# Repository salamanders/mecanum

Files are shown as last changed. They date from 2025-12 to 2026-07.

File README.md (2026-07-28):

# Robot Twin Stick Controller

4 mecanum wheel robot controlled by a twin stick controller UI.

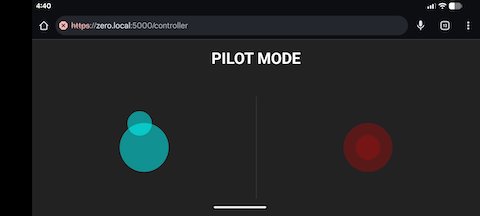
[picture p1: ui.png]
ui


## System Architecture

```mermaid
graph TD
    subgraph Client ["Client Device (Phone / Control Device)"]
        UI["controller.html (Manual twin-stick UI)"]
        Sensor["sensor.html (Sends Phone Compass data)"]
        Face["face.html (Planned: Face/Vision client)"]:::planned
    end

    subgraph Backend ["Raspberry Pi Server (app.py)"]
        Flask["Flask & SocketIO Server"]
        Wifi["WifiManager (wifi_manager.py)"]
        Driver["MotorDriver (motor_driver.py)"]
        Auto["Auto Mode Controller (Planned)"]:::planned
    end

    subgraph Hardware ["Robot Hardware"]
        I2C["I2C Bus"]
        Motors["Motors (M1, M2, M3, M4)"]
    end

    UI -- "joystick_data" --> Flask
    Sensor -- "sensor_data" --> Flask
    Face -. "face_data (planned)" .-> Flask
    Flask -- "drive(speeds)" --> Driver
    Auto -. "drive(speeds)" .-> Driver
    Driver -- "I2C Commands" --> I2C
    I2C --> Motors
    Wifi -- "nmcli commands" --> OS["OS NetworkManager"]

    classDef planned stroke-dasharray: 5 5,stroke:#999,fill:#fafafa;
```

## Getting Started

### Prerequisites

* Python 3.7+
* Hardware:
    * Raspberry Pi Zero 2 W with the default Raspbian
    * Motor Bonnet
    * Mecanum wheels (4 total, 2 of each type)
    * USB Battery pack
    * USB PD (Power Delivery) Decoy Trigger (set to 9V)
    * IMU (optional) or Android Phone (Pixel 4 etc.) for compass
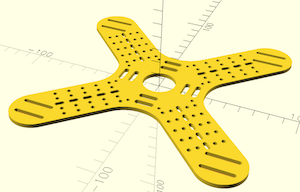
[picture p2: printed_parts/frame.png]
model
    * Some sort of frame: model included <br/> 

### System Dependencies (Raspberry Pi)

For hardware access on Raspberry Pi:

```bash
sudo raspi-config nonint do_i2c 0
```

**Wi-Fi Management:**
The robot uses `nmcli` (NetworkManager) to manage connections. Ensure it is installed:

```bash
sudo apt install network-manager
```

Then run the script in [AGENTS.md](AGENTS.md).

### Wi-Fi Fallback Mode

If the robot cannot connect to a known Wi-Fi network on boot, it will create a Hotspot:

* **SSID:** `RobotHotspot`
* **Password:** `password`
* **IP:** `10.42.0.1` (usually)

Connect your phone to this hotspot, then visit:
`http://10.42.0.1:5000/wifi`

From there, you can scan for networks and configure the robot to connect to a new location.

```mermaid
flowchart TD
    Start([System Boot]) --> CheckFlag{force_hotspot.flag exists?}
    
    CheckFlag -- Yes --> CheckLog{wifi.log writable?}
    CheckLog -- No --> PrintErr["Log error to stderr"] --> BootWait["Wait boot_wait (15s)"]
    CheckLog -- Yes --> ConsumeFlag{Can delete flag file?}
    
    ConsumeFlag -- Yes --> ForceHotspot["Set force_hotspot = True"] --> ForceAP["Trigger ensure_hotspot() immediately"]
    ConsumeFlag -- No --> LogErr["Log permission error"] --> BootWait
    
    CheckFlag -- No --> BootWait
    
    BootWait --> NormalLoop["Start normal monitoring loop"]
    NormalLoop --> QueryStatus["Query connection status"]
    
    QueryStatus --> Connected{Connected to Wi-Fi?}
    Connected -- Yes --> LoopSleep["Sleep check_interval (30s)"] --> QueryStatus
    Connected -- No --> ActivateAP["Trigger ensure_hotspot()"] --> LoopSleep
    
    ForceAP --> LoopSleep
```

#### Forcing Hotspot Mode

There are two easy ways to force the robot into Hotspot mode:

1. **Web UI Button (Instant Switch):** Visit `https://<ip>:5000/wifi` while connected and click the **"Switch to Hotspot"** button. The robot instantly switches to `RobotHotspot` mode without requiring a reboot, and writes `force_hotspot.flag` for one-time boot persistence.
2. **Command / Flag File (One-Time Boot Force):** Touch `force_hotspot.flag` in the project root directory:
   ```bash
   touch force_hotspot.flag
   ```
   On the next boot, `wifi_monitor.py` will detect the flag, immediately delete it to prevent lockout loops, and boot straight into hotspot mode. On subsequent reboots, normal Wi-Fi auto-connect resumes.
   * **Permissions Note:** The Linux user running the robot service (defined as `User` in `robot.service`, typically `pi`) must have write/delete permissions in the project root directory to delete the flag file and log to `wifi.log`.

### Installation

1. Clone the repo.
2. Install Python dependencies:

```bash
make install
```

### Running the Robot

Start the server:

```bash
make run
```

Then visit `https://zero.local:5000/controller` on your phone.

### Auto-Start Service

To run the robot automatically on boot, see [AUTO_RUN.md](AUTO_RUN.md).

### Development & Mock Mode

By default, motor control supports mock execution via `force_mock.flag` or command line flags when hardware is disconnected.

For Wi-Fi management, `WifiManager` operates directly via `nmcli` without internal fake mock state branches. If `nmcli` is not installed (e.g. running locally on a non-Linux development laptop), `WifiManager` returns clean error status responses without crashing or corrupting state.

To force mock mode for motor drivers during local development:

1. Create a `force_mock.flag` file in the project root:
   ```bash
   touch force_mock.flag
   ```
2. Run the application (`make run` or `python3 app.py`).
3. The server detects the flag, deletes it, and runs motor drivers in mock mode for that session.

To lint the code:

```bash
make lint
```

### Testing

To test motor mappings (or check Mock output):

```bash
make test
```

## Hardware Setup

* **Power**: Set USB PD Trigger to 9V.
* **Layout**: Ensure Mecanum wheels form an 'X' pattern from the top.
* **Wiring**: Connect your 4 motor channels to terminals M1-M4. Run `python3 wiring_check.py` to interactively calibrate motor channel positions and spin directions without physically rewiring.

## Files

### Backend & Hardware

* `app.py`: Main Flask application. Handles SocketIO communication, robot state management, and HTTPS certificate
  generation.
* `motor_driver.py`: Hardware abstraction layer. Handles `adafruit-circuitpython-motorkit` interaction, configurable motor channel/direction mapping, and automatic Mock fallback.
* `wiring_check.py`: Interactive calibration wizard to test channels, assign motor positions and rotation directions, and generate `motor_config.json`.

### Frontend

* `templates/`
    * `controller.html`: The Twin-Stick Joystick UI structure.
    * `sensor.html`: The Sensor Client UI structure (for transmitting phone compass/accelerometer data).
* `static/js/`
    * `common.js`: Shared logic for SocketIO connection and UI status updates.
    * `controller.js`: Handles Nipple.js joystick input and transmission.
    * `sensor.js`: Handles DeviceOrientation/Motion events and permission requests (iOS support).

### Configuration

* `Makefile`: Shortcuts for common commands (`install`, `run`, `test`, `lint`).
* `motor_config.json`: Recorded channel mapping and direction inversion config (generated by `wiring_check.py`).
* `pyproject.toml`: Python dependency management and project configuration.

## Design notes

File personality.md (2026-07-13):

# Robot Personality & Autonomous Vision Design

## Overview

This document describes the design for the robot's "Personality" system, which uses a permanently mounted Android phone
to act as the robot's face, sensor package, and autonomous brain.

The system adds expressiveness via an animated eye display and enables autonomous "chasing" behavior using web-based
computer vision, while maintaining a safety override for manual control.

## Hardware Setup

- **Device:** Android Phone (permanent fixture).
- **Mount:** Forward-facing, displaying the screen to the world (acting as "Eyes") and using the rear camera for vision.
- **Connectivity:** Connected to the robot's local Wi-Fi, accessing the web interface.

## Software Architecture

### 1. Unified Client Interface (`face.html`)

A single web page serves three distinct roles:

1. **The Face:** Displays animated eyes (CSS/SVG) that react to robot state and look at detected objects.
2. **The Sensor:** Reads device IMU data (DeviceMotion/DeviceOrientation) for compass/gyro headers (replacing
   `sensor.html`).
3. **The Vision System:** Runs a local JavaScript Object Detection model (TensorFlow.js / COCO-SSD) to detect people or
   objects.

### 2. Autonomous Logic (Client-Side)

- **Object Detection:** The phone captures video frames and processes them locally using TF.js.
- **Target Selection:** The logic selects the "most interesting" object (e.g., the largest "person" or a specific
  color).
- **Data Transmission:** The client sends a `face_data` packet to the backend ~100ms:
  ```json
  {
    "alpha": 120.5,       // Compass heading (from IMU)
    "beta": 10.2,         // Pitch (from IMU)
    "gamma": -5.0,        // Roll (from IMU)
    "vision": {
      "detected": true,
      "type": "person",
      "x": 0.5,           // Normalized X center (0.0 - 1.0)
      "y": 0.4,           // Normalized Y center (0.0 - 1.0)
      "size": 0.3         // Normalized area/height
    }
  }
  ```

### 3. Backend Logic (`app.py`)

The Python backend handles the "Safety Override" and kinematic control.

#### Safety Arbitration

- **Rule:** Human control via `/controller` always takes precedence.
- **Mechanism:**
    - A timestamp `last_human_command_time` is updated whenever a joystick event is received.
    - If `current_time - last_human_command_time < 60 seconds`:
        - **Manual Mode:** The robot ignores `vision` driving commands.
        - The `robot_status` broadcast includes `"mode": "manual"`.
    - If `current_time - last_human_command_time >= 60 seconds`:
        - **Autonomous Mode:** The robot calculates motor speeds based on `vision` data.
        - The `robot_status` broadcast includes `"mode": "auto"`.

```mermaid
stateDiagram-v2
    [*] --> ManualMode : System Start
    
    state ManualMode {
        [*] --> Idle
        Idle --> Moving : Joystick Input Received
        Moving --> Idle : Joystick Stopped
    }

    ManualMode --> AutoMode : 60 Seconds of Inactivity (No Joystick Inputs)
    
    state AutoMode {
        [*] --> Scanning
        Scanning --> Chasing : Object Detected
        Chasing --> Scanning : Target Lost
    }

    AutoMode --> ManualMode : Joystick Input Received (Manual Override)
```

#### Chasing Behavior (Auto Mode)

- **Turn:** Proportional control to center the object (Target X = 0.5).
- **Drive:** Proportional control to maintain a target size (e.g., move forward if size < 0.5, stop if close).

## Visual Personality

- **Idle/Manual Mode:** Eyes look around randomly or track the last known heading.
- **Auto Mode:** Eyes "lock on" to the detected object (tracking X/Y coordinates).
- **Reactions:**
    - Squint when moving fast.
    - Blink randomly.
    - Change color/shape based on "mode" (e.g., Blue for Manual, Red for Auto/Chasing).

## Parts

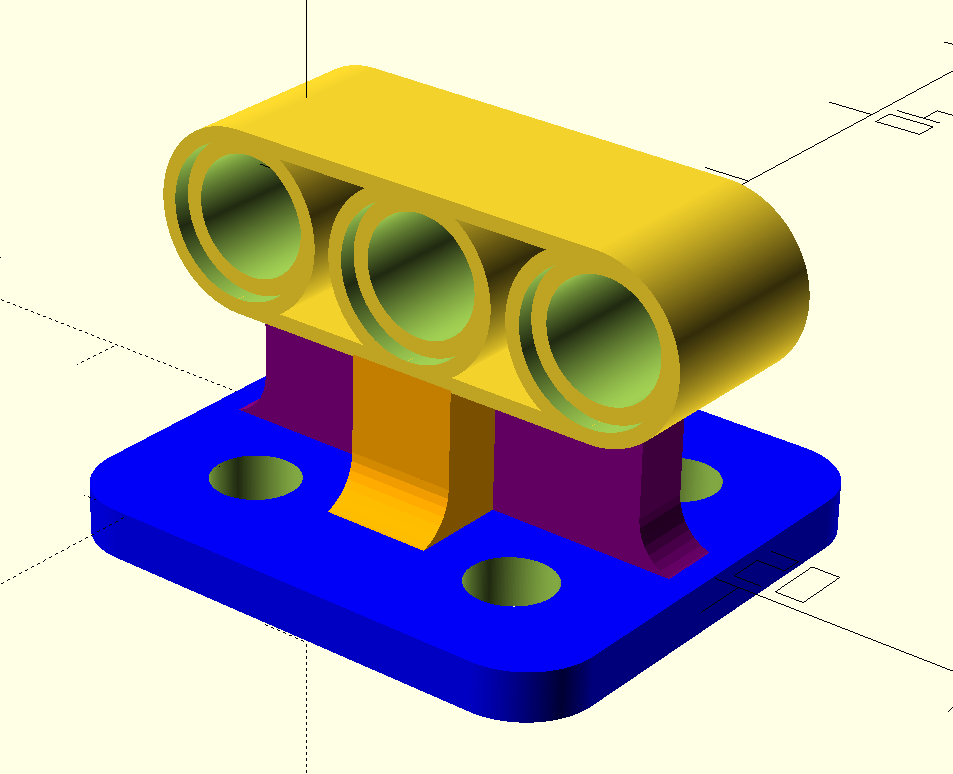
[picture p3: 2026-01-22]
printed_parts/motor_technic.png

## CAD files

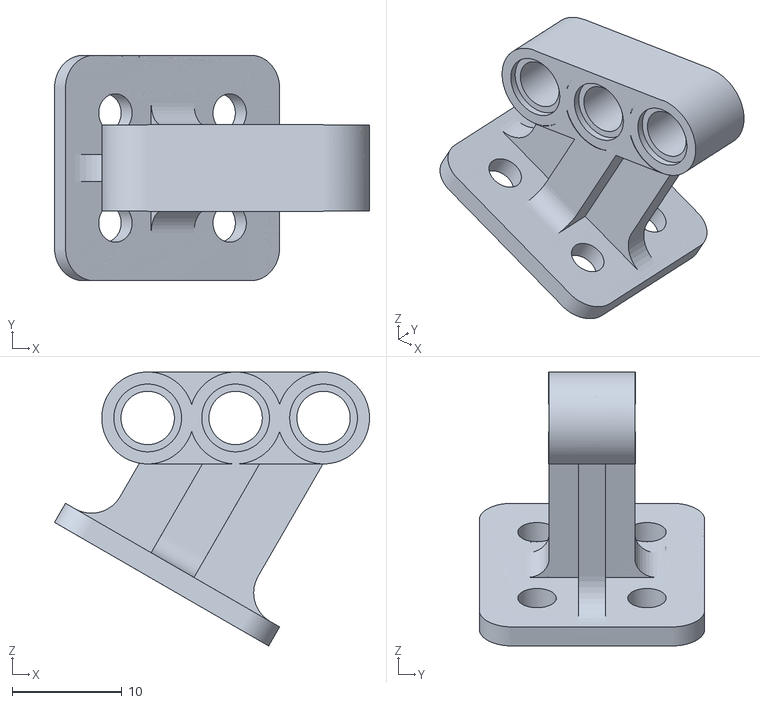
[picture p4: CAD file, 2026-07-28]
printed_parts/motor_technic.stl
28.7 x 20.5 x 24.9

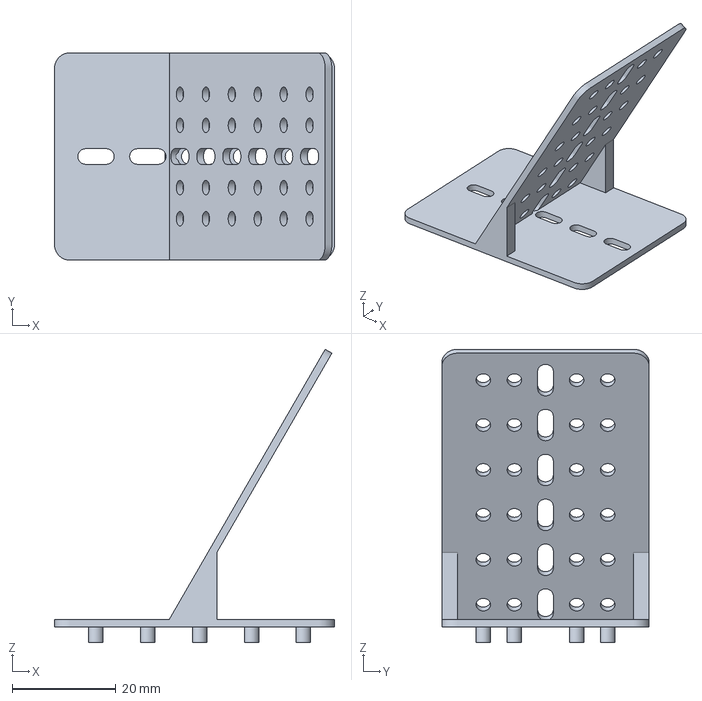
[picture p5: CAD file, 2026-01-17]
printed_parts/angled_clip.3mf
54.0 x 40.0 x 56.6 mm

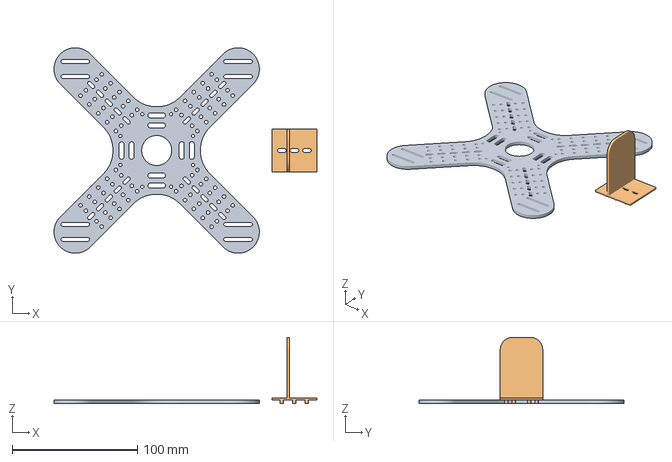
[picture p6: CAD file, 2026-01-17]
printed_parts/frame.3mf
210.0 x 164.0 x 53.0 mm

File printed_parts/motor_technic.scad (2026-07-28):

include <Technic.scad>
include <BOSL2/std.scad>

plate_height = 2;
neck_height = 6;
conn_h = 20; // Extended height to reach across the 30-degree tilt

// Square of 4 screw holes, measuring from the edges of the holes.
screw_outer_dist_x = 15.5;
screw_inner_dist_x = 8.5;

screw_outer_dist_y = 13.5;
screw_inner_dist_y = 6.5;

screw_d = 3.5;

technic_pin_connector_outer_diameter = 7.36 + 1;
technic_pin_connector_shoulder_wall_thickness = 0.6 + 0.5;

//technic_pin_connector_outer_diameter = 9.36;
//technic_pin_connector_shoulder_wall_thickness = 1.6;

union() {
    // Yellow Technic Beam
    translate([4.5,0,0])
    translate([0, technic_height_in_mm/2, technic_beam_hole_spacing/2 + neck_height - 0.4])
    rotate([90,0,0])
    technic_beam(length = 3);

    // Connectors: Built on top of the rotated plate surface and trimmed flat at neck_height
    difference() {
        rotate([0,30,0]) {
            // Orange Connector
            color("orange")
            translate([screw_outer_dist_x/2, 0, 0.1 + conn_h/2])
            cuboid(
                [screw_inner_dist_x - 4, technic_height_in_mm, conn_h], 
                rounding = -2,
                edges = [BOT], 
                except = [LEFT, RIGHT],
                $fn = 36
            );

            // Purple Connectors
            p_adjust = -1.0;
            
            color("purple")
            translate([screw_outer_dist_x/2, 0, 0.1 + conn_h/2])
            cube([screw_outer_dist_x + p_adjust, screw_inner_dist_y - 4, conn_h], center = true);

            color("purple")
            translate([screw_outer_dist_x/2, 0, 0.1 + conn_h/2])
            cuboid(
                [screw_outer_dist_x + p_adjust, screw_inner_dist_y - 4, conn_h], 
                rounding = -3,
                edges = [BOT], 
                except = [FRONT, BACK],
                $fn = 36
            );
        }

        // Trim any connector material extending above the top neck line (Z >= neck_height)
        translate([0, 0, neck_height + 25])
        cube([100, 100, 50], center = true);
    }

    // Blue Plate
    rotate([0,30,0])
    translate([0, -screw_d - screw_inner_dist_y/2, -plate_height + 0.1])
    difference() {
        color("blue")
        translate([screw_outer_dist_x/2, screw_outer_dist_y/2, plate_height/2])
        cuboid(
            [screw_outer_dist_x + 2*screw_d, screw_outer_dist_y + 2*screw_d, plate_height], 
            rounding = 3, 
            except = [TOP, BOT]
        );

        translate([0, 0, -1]) {
            translate([screw_d/2, screw_d/2, 0])
            cylinder(h = 5, d = screw_d);

            translate([screw_d/2, screw_outer_dist_y - screw_d/2, 0])
            cylinder(h = 5, d = screw_d);

            translate([screw_outer_dist_x - screw_d/2, screw_d/2, 0])
            cylinder(h = 5, d = screw_d);

            translate([screw_outer_dist_x - screw_d/2, screw_outer_dist_y - screw_d/2, 0])
            cylinder(h = 5, d = screw_d);
        }
    }
}

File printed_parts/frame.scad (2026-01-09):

// --- PARAMETERS ---
bed_size = 200;
$fn = 90;

// Chassis Dimensions
wheelbase = 130;  
arm_width = 34;   // Slightly wider to accommodate the hole grid
thickness = 3;    
fillet_radius = 25; // Bigger fillets for the "organic/tech" look

// Motor Mount Details
slot_width = 3.0; 
slot_length = 20;
slot_separation = 12; 

// Raspberry Pi Zero Mounting
pi_w = 23;        
pi_l = 58;        
pi_hole_dia = 2.6; 

// Grid System Parameters
grid_spacing = 10; // Standard 10mm spacing
m3_hole = 2.9;     // Loose fit for M3 screws

// --- MAIN RENDER ---
/*
linear_extrude(height = thickness) {
    difference() {
        
        // 1. POSITIVE SHAPE (The Body)
        offset(r = -fillet_radius) offset(r = fillet_radius)
        union() {
            // Central Hub
            circle(r=35);
            
            // The Arms
            for(i = [45, 135, 225, 315]) {
                rotate([0, 0, i])
                hull() {
                    translate([10,0]) circle(r=arm_width/2); // Blend into hub
                    translate([wheelbase/sqrt(2), 0]) circle(r=arm_width/2);
                }
            }
        }

        // 2. NEGATIVE SHAPES (The Cutouts)
        
        // --- A. Raspberry Pi Zero Mount ---
        for (x_sign = [-1, 1], y_sign = [-1, 1]) {
             translate([x_sign*pi_l/2, y_sign*pi_w/2]) circle(d=pi_hole_dia);
             translate([x_sign*pi_w/2, y_sign*pi_l/2]) circle(d=pi_hole_dia); // Rotated option
        }
        
        // Center Wire Pass-through
        circle(r=12);

        // --- B. The "Reactor" Battery Strap Slots ---
        // Large slots near the center for velcro straps (holding the battery bank)
        for(i = [0, 90, 180, 270], dist=[28, 20]) {
            rotate([0, 0, i])
            translate([dist, 0])
            hull() {
                translate([0, 5]) circle(d=4);
                translate([0, -5]) circle(d=4);
            }
        }

        // --- C. Motor Slots (Critical) ---
        for(i = [45, 135, 225, 315]) {
            rotate([0, 0, i])
            translate([wheelbase/sqrt(2) - 0, 0]) {
                rotate([0,0,-i]) {
                translate([-slot_length/2, slot_separation/2])
                # hull() { circle(d=slot_width); translate([slot_length, 0]) circle(d=slot_width); }
                
                translate([-slot_length/2, -slot_separation/2])
                # hull() { circle(d=slot_width); translate([slot_length, 0]) circle(d=slot_width); }
                }
            }
        }

        // --- D. The "Future-Proof" Grid (M3 Holes & Lightening Slots) ---
        for(i = [45, 135, 225, 315]) {
            rotate([0, 0, i]) {
                // We run a loop starting from outside the hub up to the motor mounts
                for (dist = [34 : grid_spacing : wheelbase/sqrt(2) - 12]) {
                    
                    // 1. The "Side Rails" - M3 Mounting Grid
                    translate([dist, 12]) circle(d=m3_hole);
                    translate([dist, 6]) circle(d=m3_hole);
                    translate([dist, -6]) circle(d=m3_hole);
                    translate([dist, -12]) circle(d=m3_hole);
                    
                    // 2. The "Truss" - Central Lightening/Zip-tie Slots
                    // We make these slightly staggered or continuous for a "Tech" look
                    translate([dist, 0])
                    hull() {
                        translate([-2, 0]) circle(d=3); // Oval shape
                        translate([2, 0]) circle(d=3);
                    }
                }
            }
        }
    }
}
*/

module breadboard(len, pegs=false) {
    linear_extrude(height = thickness/2) {
    difference() {
        hull() {
           for(x=[0,grid_spacing*len-2], y=[-arm_width/2, arm_width/2]) {
                translate([x,y]) circle(r=3);
            }
        }
                    
        for (dist = [grid_spacing/2 : grid_spacing : grid_spacing*len]) {
            
            // 1. The "Side Rails" - M3 Mounting Grid
            for(hole_y = [-12,-6,6,12]) {
                translate([dist, hole_y]) circle(d=m3_hole-0.1);
            }
            translate([dist, 0])
            hull() {
                translate([-2, 0]) circle(d=3); // Oval shape
                translate([2, 0]) circle(d=3);
            }
        }
    }
    }
    if(pegs) {
        color("green")
        translate([0,0,-thickness])
        linear_extrude(height = thickness * 1.5) {
        
            for (dist = [grid_spacing/2 : grid_spacing : grid_spacing*len]) {
                
                for(hole_y = [-12,-6,6,12]) {
                    translate([dist, hole_y]) circle(d=m3_hole-0.1);
                }
            }
        }
    }
}

// https://en.wikibooks.org/wiki/OpenSCAD_User_Manual/Primitive_Solids#polyhedron
module prism(l, w, h) {
    polyhedron(// pt      0        1        2        3        4        5
               points=[[0,0,0], [0,w,h], [l,w,h], [l,0,0], [0,w,0], [l,w,0]],
               // top sloping face (A)
               faces=[[0,1,2,3],
               // vertical rectangular face (B)
               [2,1,4,5],
               // bottom face (C)
               [0,3,5,4],
               // rear triangular face (D)
               [0,4,1],
               // front triangular face (E)
               [3,2,5]]
               );}
union() {     
color("blue")
translate([18.3,-17,0])
rotate([0,0,-90])
prism(3, 10, 10 * sqrt(3));

color("blue")
translate([18.3,20,0])
rotate([0,0,-90])
prism(3, 10, 10 * sqrt(3));

breadboard(5, true);

difference() {
translate([grid_spacing*2, 0, 0])
rotate([0,-60,0])
breadboard(6, false);
translate([0,0,-arm_width/2])
cube([arm_width+10, arm_width+10, arm_width], center=true);
}
}

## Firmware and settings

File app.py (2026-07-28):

import math
import os
import socket
from dataclasses import dataclass
from typing import TypedDict, Optional, Dict, Any

from OpenSSL import crypto
from flask import Flask, render_template, request, jsonify
from flask_socketio import SocketIO

from motor_driver import MotorDriver, MotorSpeeds
from wifi_manager import WifiManager
from wifi_monitor import monitor_wifi_loop


# --- TYPES & DATA CLASSES ---


@dataclass
class RobotState:
    """Stores the current state of the robot sensors."""

    heading: float = 0.0
    ax: float = 0.0
    ay: float = 0.0
    az: float = 0.0


@dataclass
class JoystickInput:
    """Represents the input from the twin-stick controller."""

    lx: float  # Left Stick X (Strafe)
    ly: float  # Left Stick Y (Drive)
    rx: float  # Right Stick X (Rotate)


class StatusData(TypedDict):
    """Type definition for the status update payload."""

    url: str
    battery: Optional[str]


# --- LOGIC HELPERS ---


def calculate_mecanum_speeds(
        input_data: JoystickInput, heading_degrees: float
) -> MotorSpeeds:
    """
    Calculates the motor speeds for a mecanum wheel robot with field-centric control.

    :param input_data: Joystick inputs (lx, ly, rx)
    :param heading_degrees: Current robot heading in degrees
    :return: MotorSpeeds object with normalized throttle values
    """
    # 1. Field-Centric Math
    # Convert degrees to radians
    theta = math.radians(-heading_degrees)

    # Rotate the vector
    # We counteract the robot's rotation to keep inputs "Field Aligned"
    field_x = input_data.lx * math.cos(theta) - input_data.ly * math.sin(theta)
    field_y = input_data.lx * math.sin(theta) + input_data.ly * math.cos(theta)

    # 2. Mecanum Kinematics
    # front_left = y + x + rot
    front_left = field_y + field_x + input_data.rx
    front_right = field_y - field_x - input_data.rx
    back_left = field_y - field_x + input_data.rx
    back_right = field_y + field_x - input_data.rx

    # 3. Normalize
    # Ensure no value exceeds 1.0 while maintaining proportions
    maximum = max(
        abs(front_left), abs(front_right), abs(back_left), abs(back_right), 1.0
    )

    return MotorSpeeds(
        front_left=front_left / maximum,
        front_right=front_right / maximum,
        back_left=back_left / maximum,
        back_right=back_right / maximum,
    )


def get_local_ip() -> str:
    """Detects the local IP address of the machine."""
    s = None
    try:
        s = socket.socket(socket.AF_INET, socket.SOCK_DGRAM)
        # doesn't even have to be reachable if default route exists
        s.connect(("8.8.8.8", 1))
        ip_address = s.getsockname()[0]
    except Exception:
        ip_address = "127.0.0.1"
        try:
            if "wifi" in globals() and wifi:
                status_ip = wifi.get_status().get("ip")
                if status_ip:
                    ip_address = status_ip
        except Exception:
            pass
    finally:
        if s:
            s.close()
    return str(ip_address)


# --- FLASK SETUP ---

app = Flask(__name__)
# key for security, not critical for LAN but required by Flask
app.config["SECRET_KEY"] = "robot_secret"
socketio = SocketIO(app, cors_allowed_origins="*")

# --- GLOBAL STATE ---

# Check and consume the force_mock.flag file once for both drivers
flag_path = "force_mock.flag"
force_mock = False
if os.path.exists(flag_path):
    try:
        os.remove(flag_path)
        force_mock = True
        print("Forcing MOCK mode for this launch.")
    except Exception as e:
        print(f"Failed to delete force_mock.flag ({e}). Ignoring mock flag.")

robot_state = RobotState()
motors = MotorDriver(mock=force_mock)
wifi = WifiManager(mock=force_mock)


def send_status_update(target_sid: Optional[str] = None) -> None:
    """
    Broadcasts or sends a status update to a specific client.
    Includes the Controller URL and battery status.
    """
    ip = get_local_ip()
    url = f"https://{ip}:5000/controller"

    data: StatusData = {
        "url": url,
        "battery": None,  # Placeholder for battery level
    }

    if target_sid:
        socketio.emit("robot_status", data, room=target_sid)
    else:
        socketio.emit("robot_status", data)


def background_status_task() -> None:
    """Background task to send status updates every 60 seconds."""
    while True:
        socketio.sleep(60)
        send_status_update()


# --- ROUTES ---


@app.route("/controller")
def controller() -> str:
    return render_template("controller.html")


@app.route("/sensor")
def sensor() -> str:
    return render_template("sensor.html")


@app.route("/wifi")
def wifi_page() -> str:
    return render_template("wifi.html")


@app.route("/api/wifi/scan")
def api_wifi_scan():
    """Returns list of available networks."""
    networks = wifi.scan_networks()
    return jsonify(
        [{"ssid": n.ssid, "signal": n.signal, "security": n.security} for n in networks]
    )


@app.route("/api/wifi/connect", methods=["POST"])
def api_wifi_connect():
    """Connects to a specific network."""
    data = request.json
    ssid = data.get("ssid")
    password = data.get("password")

    if not ssid:
        return jsonify({"success": False, "message": "SSID required"}), 400

    success, msg = wifi.connect_to(ssid, password)
    return jsonify({"success": success, "message": msg})


@app.route("/api/wifi/status")
def api_wifi_status():
    """Returns current connection info."""
    return jsonify(wifi.get_status())


@app.route("/api/wifi/hotspot", methods=["POST"])
def api_wifi_hotspot():
    """Forces robot into Access Point / Hotspot mode."""
    flag_path = "force_hotspot.flag"
    try:
        with open(flag_path, "w") as f:
            f.write("1\n")
        print(f"app: Created {flag_path} for boot persistence.")
    except Exception as e:
        print(f"app: Failed to write {flag_path} ({e})")

    success, msg = wifi.ensure_hotspot(force=True)
    return jsonify({"success": success, "message": msg})




# --- WEBSOCKET LISTENERS ---


@socketio.on("connect")
def handle_connect() -> None:
    # Send status immediately upon connection
    send_status_update(request.sid)


@socketio.on("sensor_data")
def handle_sensor(data: Dict[str, Any]) -> None:
    """
    Receives sensor data from the phone/client.
    Expected data: heading, ax, ay, az
    """
    # Note: Android 'alpha' is 0=North, increasing counter-clockwise usually
    robot_state.heading = float(data.get("heading", 0))
    robot_state.ax = float(data.get("ax", 0))
    robot_state.ay = float(data.get("ay", 0))
    robot_state.az = float(data.get("az", 0))


@socketio.on("joystick_data")
def handle_joystick(data: Dict[str, Any]) -> None:
    """
    Receives joystick input and drives the motors.
    Expected data: lx, ly, rx
    """
    # 1. Parse Input (with defaults)
    input_data = JoystickInput(
        lx=float(data.get("lx", 0)),
        ly=float(data.get("ly", 0)),  # Up should be positive
        rx=float(data.get("rx", 0)),  # Right should be positive
    )

    # 2. Calculate Speeds
    speeds = calculate_mecanum_speeds(input_data, robot_state.heading)

    # 3. Execute
    motors.drive(speeds)


def ensure_certificates() -> None:
    """
    Generates self-signed 'cert.pem' and 'key.pem' if they do not exist.
    This ensures HTTPS works out-of-the-box for DeviceOrientation API support.
    """
    cert_file = "cert.pem"
    key_file = "key.pem"

    if os.path.exists(cert_file) and os.path.exists(key_file):
        return

    print("Generating self-signed certificates for HTTPS...")
    k = crypto.PKey()
    k.generate_key(crypto.TYPE_RSA, 2048)

    cert = crypto.X509()
    cert.get_subject().C = "US"
    cert.get_subject().ST = "RobotState"
    cert.get_subject().L = "RobotCity"
    cert.get_subject().O = "Robot"
    cert.get_subject().OU = "RobotUnit"
    cert.get_subject().CN = "robot.local"
    cert.set_serial_number(1000)
    cert.gmtime_adj_notBefore(0)
    cert.gmtime_adj_notAfter(10 * 365 * 24 * 60 * 60)
    cert.set_issuer(cert.get_subject())
    cert.set_pubkey(k)
    cert.sign(k, "sha256")

    with open(cert_file, "wt") as f:
        f.write(crypto.dump_certificate(crypto.FILETYPE_PEM, cert).decode("utf-8"))
    with open(key_file, "wt") as f:
        f.write(crypto.dump_privatekey(crypto.FILETYPE_PEM, k).decode("utf-8"))
    print(f"Certificates generated: {cert_file}, {key_file}")


if __name__ == "__main__":
    # Ensure SSL certs exist (required for modern browser sensors)
    ensure_certificates()

    # Start background tasks
    socketio.start_background_task(background_status_task)
    # Start wifi monitor in background (waits 15s then checks connectivity)
    # Pass socketio.sleep to prevent blocking the event loop
    socketio.start_background_task(
        monitor_wifi_loop,
        sleep_func=socketio.sleep,
        wifi_manager=wifi,
    )

    # Host 0.0.0.0 makes it accessible on the LAN
    socketio.run(app, host="0.0.0.0", port=5000, certfile="cert.pem", keyfile="key.pem")

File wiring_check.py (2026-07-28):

import json
import os
import sys

from motor_driver import MotorDriver

CONFIG_FILE = "motor_config.json"

POSITIONS = [
    ("front_left", "Front-Left"),
    ("front_right", "Front-Right"),
    ("back_left", "Back-Left"),
    ("back_right", "Back-Right"),
]

DIRECTIONS = [
    ("forward", "Forward (Regular)", False),
    ("backward", "Backward (Inverted)", True),
]


def prompt_choice(prompt_text: str, num_options: int) -> int:
    """Prompts the user to select an integer option between 1 and num_options."""
    while True:
        try:
            choice_str = input(prompt_text).strip()
            if choice_str.isdigit():
                choice = int(choice_str)
                if 1 <= choice <= num_options:
                    return choice
            print(f"   [!] Invalid choice. Please enter a number between 1 and {num_options}.")
        except (KeyboardInterrupt, EOFError):
            print("\n   Aborted by user.")
            raise


def main():
    print("==================================================")
    print("        INTERACTIVE MOTOR MAPPING WIZARD          ")
    print("==================================================")
    print("This wizard will test each of the 4 motor channels (M1-M4).")
    print("For each channel, a motor will run at 50% power,")
    print("and you will specify which physical motor it is and")
    print("whether it is spinning forward or backward.")
    print("==================================================")

    # Check and consume force_mock.flag or sys.argv
    flag_path = "force_mock.flag"
    force_mock = False
    if "--mock" in sys.argv or "-m" in sys.argv:
        force_mock = True
        print("Forcing MOCK mode via command line flag.")
    elif os.path.exists(flag_path):
        try:
            os.remove(flag_path)
            force_mock = True
            print("Forcing MOCK mode from force_mock.flag.")
        except Exception as e:
            print(f"Failed to delete force_mock.flag ({e}). Ignoring mock flag.")

    driver = MotorDriver(mock=force_mock, config_path=CONFIG_FILE)

    channel_mapping = {}

    try:
        for ch in range(1, 5):
            print("\n--------------------------------------------------")
            print(f"STEP {ch}/4: Testing Motor Channel M{ch}")
            print("--------------------------------------------------")
            print(
                f" -> Spinning Motor Channel M{ch} at 50% throttle "
                "(will stay running until choices are submitted)..."
            )
            driver.drive_channel(ch, 0.5)

            # 1. Ask which motor position
            print(f"\nWhich motor was running on Channel M{ch}?")
            for idx, (_, display_name) in enumerate(POSITIONS, 1):
                print(f"  {idx}. {display_name}")

            pos_idx = prompt_choice(
                f"Select motor position [1-{len(POSITIONS)}]: ", len(POSITIONS)
            )
            pos_key, pos_display = POSITIONS[pos_idx - 1]

            # Re-assert motor spin to be 100% sure hardware PWM stays active
            driver.drive_channel(ch, 0.5)

            # 2. Ask direction (forward or backward)
            print(f"\nWas the {pos_display} motor running forward or backward?")
            for idx, (_, display_name, _) in enumerate(DIRECTIONS, 1):
                print(f"  {idx}. {display_name}")

            dir_idx = prompt_choice(
                f"Select direction [1-{len(DIRECTIONS)}]: ", len(DIRECTIONS)
            )
            dir_key, dir_display, is_inverted = DIRECTIONS[dir_idx - 1]

            # Stop channel only after both selections are made
            driver.drive_channel(ch, 0.0)
            print(f" -> Stopped Motor Channel M{ch}.")

            channel_mapping[str(ch)] = {
                "position": pos_key,
                "inverted": is_inverted,
                "label": pos_display,
                "direction": dir_key,
            }

            print(f"Recorded: Channel M{ch} => {pos_display} ({dir_display})")

        # Save to motor_config.json
        config_data = {"channels": channel_mapping}

        with open(CONFIG_FILE, "w") as f:
            json.dump(config_data, f, indent=2)

        print("\n==================================================")
        print("          MOTOR MAPPING COMPLETE                  ")
        print("==================================================")
        print(f"Configuration saved to '{CONFIG_FILE}':\n")
        for ch_str, info in channel_mapping.items():
            dir_str = (
                "Backward (Inverted)" if info["inverted"] else "Forward (Regular)"
            )
            print(f"  Channel M{ch_str}: {info['label']:<12} | Direction: {dir_str}")
        print("==================================================")
        print("\nTo apply this configuration to a background app instance, run:")
        print("  sudo systemctl restart robot.service\n")

    except KeyboardInterrupt:
        print("\n\nMapping cancelled by user! Stopping all motors...")
    except Exception as e:
        print(f"\n\nAn error occurred during mapping: {e}")
    finally:
        try:
            driver.stop()
        except Exception:
            pass
        print("Motors safely stopped.")


if __name__ == "__main__":
    main()

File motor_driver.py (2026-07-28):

import json
import os
from dataclasses import dataclass
from typing import Dict, Optional, Protocol, Any

# Type Alias for clarity
ThrottleValue = float


class MotorKitProtocol(Protocol):
    """Protocol for the MotorKit object to support Mocking cleanly."""

    class Motor(Protocol):
        throttle: Optional[ThrottleValue]

    motor1: Motor
    motor2: Motor
    motor3: Motor
    motor4: Motor


@dataclass
class MotorSpeeds:
    """Represents the throttle values for the 4 mecanum wheels."""

    front_left: float
    front_right: float
    back_left: float
    back_right: float


# Default mapping if motor_config.json does not exist
DEFAULT_MOTOR_CONFIG: Dict[str, Dict[str, Any]] = {
    "1": {"position": "front_left", "inverted": False},
    "2": {"position": "front_right", "inverted": False},
    "3": {"position": "back_left", "inverted": False},
    "4": {"position": "back_right", "inverted": False},
}


class MotorDriver:
    """
    Handles motor control.
    Supports motor mapping & inversion configuration via motor_config.json.
    Automatically falls back to a Mock implementation if hardware is missing.
    """

    def __init__(self, mock: bool = False, config_path: str = "motor_config.json") -> None:
        self.mock: bool = mock
        self.config_path: str = config_path
        self.config: Dict[str, Dict[str, Any]] = self.load_config(config_path)
        self.kit: Optional[MotorKitProtocol] = None

        if self.mock:
            print("MotorDriver: Running in MOCK mode.")
            return

        from adafruit_motorkit import MotorKit

        # The Adafruit Bonnet usually lives at address 0x60
        self.kit = MotorKit()
        print("Adafruit Motor Bonnet Connected!")

    def load_config(self, path: str) -> Dict[str, Dict[str, Any]]:
        """Loads motor mapping configuration from file or falls back to default."""
        if os.path.exists(path):
            try:
                with open(path, "r") as f:
                    data = json.load(f)
                    if "channels" in data and isinstance(data["channels"], dict):
                        print(f"MotorDriver: Loaded motor mapping config from {path}")
                        return data["channels"]
                    elif isinstance(data, dict):
                        print(f"MotorDriver: Loaded motor mapping config from {path}")
                        return data
            except Exception as e:
                print(f"MotorDriver: Failed to load config from {path} ({e}). Using defaults.")
        return DEFAULT_MOTOR_CONFIG.copy()

    def drive_channel(self, channel: int, throttle: float) -> None:
        """
        Drives a raw motor channel (1-4) directly at the specified throttle (-1.0 to 1.0).
        """
        def _clamp(val: float) -> float:
            return max(-1.0, min(1.0, val))

        clamped = _clamp(throttle)

        if self.mock or self.kit is None:
            print(f"MOCK DRIVE CHANNEL {channel}: throttle={clamped:.2f}")
            return

        if channel == 1:
            self.kit.motor1.throttle = clamped
        elif channel == 2:
            self.kit.motor2.throttle = clamped
        elif channel == 3:
            self.kit.motor3.throttle = clamped
        elif channel == 4:
            self.kit.motor4.throttle = clamped

    def stop(self) -> None:
        """Stops all motors on all channels."""
        self.drive_channel(1, 0.0)
        self.drive_channel(2, 0.0)
        self.drive_channel(3, 0.0)
        self.drive_channel(4, 0.0)

    def drive(self, speeds: MotorSpeeds) -> None:
        """
        Drives the motors using the provided MotorSpeeds dataclass,
        mapped according to channel configuration and inversion settings.
        """
        def _clamp(val: float) -> float:
            return max(-1.0, min(1.0, val))

        speed_map = {
            "front_left": speeds.front_left,
            "front_right": speeds.front_right,
            "back_left": speeds.back_left,
            "back_right": speeds.back_right,
        }

        # Calculate throttle for each channel 1..4 based on config
        channel_throttles: Dict[int, float] = {}
        for ch in (1, 2, 3, 4):
            ch_key = str(ch)
            ch_cfg = self.config.get(ch_key, DEFAULT_MOTOR_CONFIG.get(ch_key, {}))
            position = ch_cfg.get("position", "front_left")
            inverted = ch_cfg.get("inverted", False)

            target_speed = speed_map.get(position, 0.0)
            throttled_speed = -target_speed if inverted else target_speed
            channel_throttles[ch] = _clamp(throttled_speed)

        if self.mock or self.kit is None:
            print(
                f"MOCK DRIVE: CH1({self.config.get('1', {}).get('position', 'fl')})={channel_throttles[1]:.2f}, "
                f"CH2({self.config.get('2', {}).get('position', 'fr')})={channel_throttles[2]:.2f}, "
                f"CH3({self.config.get('3', {}).get('position', 'bl')})={channel_throttles[3]:.2f}, "
                f"CH4({self.config.get('4', {}).get('position', 'br')})={channel_throttles[4]:.2f}"
            )
            return

        self.kit.motor1.throttle = channel_throttles[1]
        self.kit.motor2.throttle = channel_throttles[2]
        self.kit.motor3.throttle = channel_throttles[3]
        self.kit.motor4.throttle = channel_throttles[4]

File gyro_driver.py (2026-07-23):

import random
import time
from dataclasses import dataclass
from typing import Optional

# Register Constants
L3G4200D_WHO_AM_I = 0x0F
L3G4200D_CTRL_REG1 = 0x20
L3G4200D_CTRL_REG2 = 0x21
L3G4200D_CTRL_REG3 = 0x22
L3G4200D_CTRL_REG4 = 0x23
L3G4200D_CTRL_REG5 = 0x24
L3G4200D_OUT_X_L = 0x28
L3G4200D_STATUS_REG = 0x27

# I2C Addresses
L3G4200D_ADDRESS_68 = 0x68
L3G4200D_ADDRESS_69 = 0x69
L3G4200D_ID = 0xD3


@dataclass
class GyroData:
    """Represents the angular velocity in degrees per second."""

    x: float
    y: float
    z: float


class GyroDriver:
    """
    Driver for L3G4200D 3-axis Gyroscope.
    Handles I2C communication, configuration, and data reading.
    Falls back to Mock mode if hardware is missing.
    """

    def __init__(self, mock: bool = False) -> None:
        self.mock: bool = mock
        self.i2c = None
        self.address: Optional[int] = None
        self.offset_x: float = 0.0
        self.offset_y: float = 0.0
        self.offset_z: float = 0.0

        if self.mock:
            print("Gyro Driver: Running in MOCK mode.")
            return

        import board
        import busio

        # Initialize I2C
        self.i2c = busio.I2C(board.SCL, board.SDA)

        # Scan for device
        self._acquire_lock()


        try:
            addresses = self.i2c.scan()
            print(f"I2C Scan found: {[hex(a) for a in addresses]}")

            if L3G4200D_ADDRESS_69 in addresses:
                self.address = L3G4200D_ADDRESS_69
            elif L3G4200D_ADDRESS_68 in addresses:
                self.address = L3G4200D_ADDRESS_68

            if self.address is None:
                raise OSError("L3G4200D not found on I2C bus.")

            # Check WHO_AM_I
            chip_id = self._read_register(L3G4200D_WHO_AM_I)
            if chip_id != L3G4200D_ID:
                print(
                    f"Warning: Unexpected Chip ID: {hex(chip_id)} (Expected {hex(L3G4200D_ID)})"
                )

            # Initialize Configuration
            self._initialize_chip()
            print(f"L3G4200D initialized at address {hex(self.address)}")

        finally:
            self.i2c.unlock()

    def _acquire_lock(self, timeout_ms: int = 100) -> None:
        """Acquires I2C bus lock with sleep and timeout to prevent CPU spin/hang."""
        if not self.i2c:
            return
        attempts = 0
        max_attempts = max(1, timeout_ms)
        while not self.i2c.try_lock():
            time.sleep(0.001)
            attempts += 1
            if attempts >= max_attempts:
                raise OSError("I2C lock timeout in GyroDriver")

    def _write_register(self, register: int, value: int) -> None:
        """Writes a byte to a specific register. Assumes I2C lock is held."""
        if self.mock or not self.i2c or not self.address:
            return

        # busio.I2C expects a bytes-like object
        # We send [Register, Value]
        buffer = bytearray([register, value])
        self.i2c.writeto(self.address, buffer)

    def _read_register(self, register: int) -> int:
        """Reads a single byte from a register. Assumes I2C lock is held."""
        if self.mock or not self.i2c or not self.address:
            return 0

        result = bytearray(1)
        self.i2c.writeto_then_readfrom(self.address, bytes([register]), result)
        return result[0]

    def _read_bytes(self, start_register: int, length: int) -> bytearray:
        """Reads multiple bytes starting from a register (asserting MSB for auto-increment). Assumes I2C lock is held."""
        if self.mock or not self.i2c or not self.address:
            return bytearray(length)

        # Set bit 7 (MSB) to 1 for auto-increment
        reg_addr = start_register | 0x80
        result = bytearray(length)
        self.i2c.writeto_then_readfrom(self.address, bytes([reg_addr]), result)
        return result

    def _initialize_chip(self) -> None:
        """Sets up the control registers. Assumes I2C lock is held."""
        # CTRL_REG1 (0x20):
        # DR1 DR0 BW1 BW0 PD Zen Yen Xen
        # 0   0   (100Hz)
        #         0   0   (Cut-off 12.5)
        #                 1   (Power ON)
        #                     1   1   1 (Enable Axes)
        # Binary: 0000 1111 -> 0x0F
        self._write_register(L3G4200D_CTRL_REG1, 0x0F)

        # CTRL_REG4 (0x23):
        # BDU BLE FS1 FS0 - ST1 ST0 SIM
        # 0   (Continuous update)
        #     0   (Little Endian)
        #         1   0   (2000 dps full scale)
        #                 0   0   0   0
        # Binary: 0010 0000 -> 0x20 No wait, FS=2000dps is FS1=1, FS0=0?
        # Datasheet: FS1-FS0: 00=250, 01=500, 10=2000, 11=2000
        # So 10 -> 0x30? No. Bit 5 and 4.
        # 7 6 5 4 3 2 1 0
        # BDU BLE FS1 FS0 - ST1 ST0 SIM
        # 0 0 1 1 0 0 0 0 -> 0x30 (2000 dps)
        self._write_register(L3G4200D_CTRL_REG4, 0x30)

    def calibrate(self, samples: int = 100) -> None:
        """
        Reads N samples to determine the zero-rate level (bias).
        Robot must be stationary.
        """
        if self.mock:
            print("MOCK Calibration: Done.")
            return

        print(f"Calibrating Gyro ({samples} samples)... DO NOT MOVE ROBOT.")
        sum_x, sum_y, sum_z = 0.0, 0.0, 0.0

        # Temporary disable offsets to read raw values
        old_ox, old_oy, old_oz = self.offset_x, self.offset_y, self.offset_z
        self.offset_x, self.offset_y, self.offset_z = 0.0, 0.0, 0.0

        try:
            for _ in range(samples):
                data = self.read_data()
                sum_x += data.x
                sum_y += data.y
                sum_z += data.z
                time.sleep(0.01)  # 10ms delay (100Hz ODR)

            self.offset_x = sum_x / samples
            self.offset_y = sum_y / samples
            self.offset_z = sum_z / samples

            print(
                f"Calibration Complete. Offsets: X={self.offset_x:.2f}, Y={self.offset_y:.2f}, Z={self.offset_z:.2f}"
            )

        except Exception as e:
            print(f"Calibration failed: {e}")
            # Restore old offsets if failed
            self.offset_x, self.offset_y, self.offset_z = old_ox, old_oy, old_oz

    def read_data(self) -> GyroData:
        """Reads the current angular velocity."""
        if self.mock:
            # Return some random noise
            return GyroData(
                x=random.uniform(-0.5, 0.5),
                y=random.uniform(-0.5, 0.5),
                z=random.uniform(-0.5, 0.5),
            )

        # Acquire lock correctly
        self._acquire_lock()

        try:
            # Read 6 bytes: XL, XH, YL, YH, ZL, ZH
            raw_bytes = self._read_bytes(L3G4200D_OUT_X_L, 6)
        finally:
            self.i2c.unlock()

        # Convert to 16-bit signed
        # struct.unpack('<hhh', raw_bytes) would be cleaner, but let's do it manually to avoid import if we can or just use struct
        import struct
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

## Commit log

2025-12-27 Formalize project structure for v0.9 release
    - Extract `MotorDriver` class to `motor_driver.py` with Mock Mode support for development without hardware.
    - Create `requirements.txt` with necessary dependencies (Flask, SocketIO, Adafruit libraries, etc.).
    - Create `pyproject.toml` for modern project metadata.
    - Add `Makefile` for easy `install`, `run`, and `test` commands.
    - Update `test_motors.py` to use the new driver abstraction.
    - Update `README.md` with comprehensive setup and usage instructions.
    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
2025-12-27 first frame
    [frame.scad]
2025-12-27 cool frame
    [frame.scad, frame.stl]
2025-12-28 fixin stuff
    [frame.3mf, frame.scad, frame.stl]
2025-12-28 Add interactive wiring check script
    This adds `wiring_check.py`, an interactive CLI tool that walks the user through
    verifying the wiring and direction of all 4 motors. It uses the `MotorDriver`
    class to power each motor individually at 50% throttle and prompts the user
    to check voltage and spin direction.
2025-12-28 modern package managers
    [frame.3mf, frame.scad]
2025-12-30 Fix lint errors and apply formatting
    Ran `make lint` which executes `ruff check` and `ruff format`.
    - Fixed unused imports in `wiring_check.py` (`time`, `sys`).
    - Fixed extraneous f-strings in `wiring_check.py`.
    - Replaced bare `except:` with `except Exception:` in `wiring_check.py`.
    - Applied standard formatting to `app.py`, `motor_driver.py`, and `wiring_check.py`.
    [app.py, motor_driver.py, wiring_check.py]
2025-12-30 Fix: Capture and print specific ImportError in motor_driver.py
    Instead of printing a generic "not installed" message, the driver now
    captures the actual ImportError exception and prints it. This helps
    diagnose issues like missing dependencies or permissions.
    Falls back to Mock Mode as before.
    [motor_driver.py]
2025-12-30 Update AUTO_RUN.md for uv and fix build structure
    - Updated `AUTO_RUN.md` to use `uv run` with explicit paths for systemd services.
    - Renamed `parts/` to `printed_parts/` to avoid conflict with Python package discovery.
    - Updated `pyproject.toml` to explicitly exclude `templates` and `printed_parts` from build.
    - Updated `README.md` references.
    [frame.3mf, frame.scad]
2026-01-04 Add RPi.GPIO and adafruit-blinka to dependencies
    Explicitly adds `RPi.GPIO` and `adafruit-blinka` to `pyproject.toml`.
    This fixes an import error (`No module named 'RPi'`) encountered when running the application on a Raspberry Pi using `uv`, which isolates the environment from system packages.
2026-01-04 docs: update README with hardware specs, lint command, and auto-start link
    Updates the README to reflect the specific hardware (Raspberry Pi Zero 2 W),
    adds the `make lint` command to the Development section, and links to
    AUTO_RUN.md for service configuration.
2026-01-04 feat: improve sensor page error handling and logging
    - Add UI status element to display connection and sensor states.
    - Implement comprehensive try/catch blocks for Wake Lock and Permissions.
    - Add structured console logging (info, warn, error, debug).
    - Add Socket.IO connection event listeners.
    - Add *.pem to .gitignore to prevent SSL cert leaks.
2026-01-04 feat: improve sensor page error handling and logging
    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
2026-01-04 Add acceleration display and controller link to sensor page
    - Update `templates/sensor.html` to display linear acceleration (X, Y, Z).
    - Update `templates/sensor.html` to show a clickable link to the Controller URL.
    - Implement throttling in `sensor.html` to send sensor data every 100ms instead of on every event.
    - Update `app.py` to handle acceleration data and broadcast status updates (URL + battery placeholder) every 60s.
    - Add `get_local_ip` helper in `app.py` to correctly identify the robot's LAN IP.
    [app.py]
2026-01-04 Refactor app for elegance and type safety
    - Introduced `dataclasses` (RobotState, JoystickInput, MotorSpeeds) for strict typing.
    - Added JSDoc type annotations to Javascript and split into `static/js/`.
    - Implemented `ensure_certificates()` to auto-generate SSL certs for out-of-the-box sensor support.
    - Extracted mecanum kinematics logic for cleaner `app.py`.
    - Updated `pyproject.toml` to exclude `static`.
    - Verified with Playwright and `ruff`.
2026-01-04 Update documentation to align with codebase structure
    - Updated `README.md` to include new frontend files (`templates/`, `static/js/`) and explain the separation of concerns.
    - Updated `AGENTS.md` to remove redundant steps (cert generation now in `app.py`) and non-existent verification scripts.
    - Verified `AUTO_RUN.md` aligns with current execution commands.
2026-01-05 Fix reversed compass logic in field-centric control
    Inverts the heading angle in `calculate_mecanum_speeds` to correctly transform Field-Centric joystick inputs into the Robot-Centric frame. Previously, the rotation was mirrored, causing the robot to move incorrectly when rotated.
    - Updated `app.py`: Negate `heading_degrees` before calculating `theta`.
    [app.py]
2026-01-06 Add L3G4200D gyro driver and interactive check script
    - Added `gyro_driver.py` with `GyroDriver` class for L3G4200D I2C communication, including mocking support.
    - Added `gyro_check.py` as an interactive CLI tool for wiring verification and calibration.
    - Driver handles I2C locking correctly and supports both standard addresses (0x68, 0x69).
    [gyro_check.py, gyro_driver.py]
2026-01-09 Clip addition to the frame
    [frame.scad]
2026-01-11 Add personality.md design doc
    Describes the architecture for the new "Face" system, including:
    - Permanent Android phone setup.
    - Unified `face.html` for Eyes + Sensors + Vision.
    - Safety override logic (Manual > Auto).
    - Autonomous "chasing" behavior using TF.js.
2026-01-17 Add Wi-Fi configuration manager and hotspot fallback
    - Added `wifi_manager.py` to wrap `nmcli` for scanning and connecting.
    - Added `wifi_monitor.py` to auto-detect disconnection and trigger `RobotHotspot` fallback.
    - Added `/wifi` route and API endpoints to `app.py`.
    - Updated `app.py` to run monitoring loop in a background task using `socketio.sleep`.
    - Added `templates/wifi.html` for network selection UI.
    - Added `tests/test_wifi.py` for unit testing logic and routes.
    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
2026-01-18 Fix: update wiring_check to use MotorSpeeds dataclass
    wiring_check.py was passing 4 positional arguments to MotorDriver.drive(), but the method expects a single MotorSpeeds object. Updated the calls to wrap arguments in MotorSpeeds.
    [wiring_check.py]
2026-01-25 new wheels for helper bot
    [tpu_wheel.scad]
2026-07-12 long time break
    [tpu_wheel.scad]
2026-07-23 fix(wifi): enhance offline hotspot fallback and interface detection
    [wifi_manager.py]
2026-07-23 fix(app): guard socket cleanup in get_local_ip and deduplicate logger handlers
    [app.py, wifi_monitor.py]
2026-07-23 fix(motor): clamp motor throttle values to [-1.0, 1.0] range
    [motor_driver.py]
2026-07-23 fix(gyro): remove invalid WHO_AM_I write and add I2C lock timeout
    [gyro_driver.py]
2026-07-28 mapped motor
2026-07-28 latest angled connector
    [motor_technic.3mf, motor_technic.scad, motor_technic.stl]
2026-07-28 how to load new wiring config.
